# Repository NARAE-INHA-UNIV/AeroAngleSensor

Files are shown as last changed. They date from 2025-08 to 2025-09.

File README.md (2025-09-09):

# AeroAngleSensor

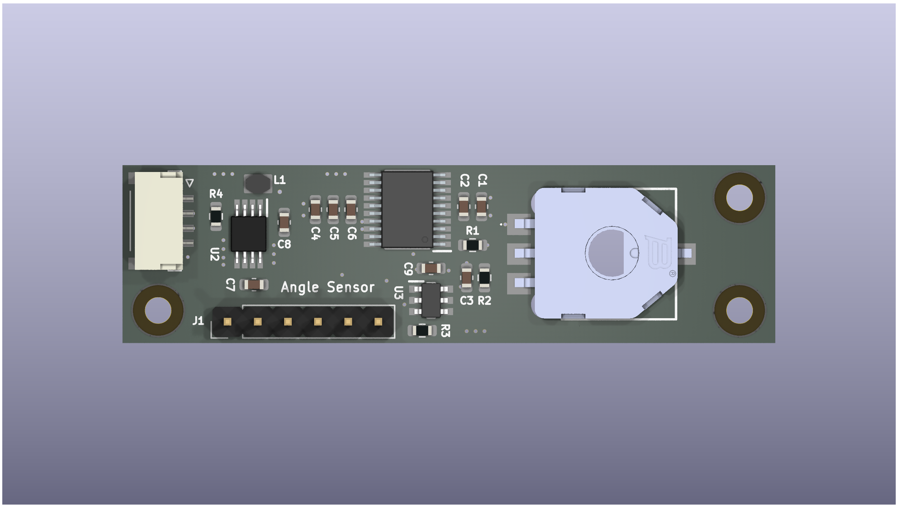
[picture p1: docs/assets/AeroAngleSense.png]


[[Youtube] 무인 항공기용 회전각 센서 시현 영상](https://www.youtube.com/watch?v=Au1dN9QMTIA)

- 일시 : 2025 1학기
- 팀명 : 항공전자, 각도발전소(인하종합설계경진대회)
- 팀장 : 김정걸
- 팀원 : 김성호, 임정섭, 이해강, 이현제

## 프로젝트 구조

```
AeroAngleSensor/
├── AeroAngleSense        # KiCAD 회로
├── AeroAngleSense.step   # 센서 step 파일
├── docs                  # docs 문서 및 이미지 에셋
├── Firmware              # 펌웨어 STM32 코드
├── LICENSE.md
├── README.md
└── Schematic.pdf
```

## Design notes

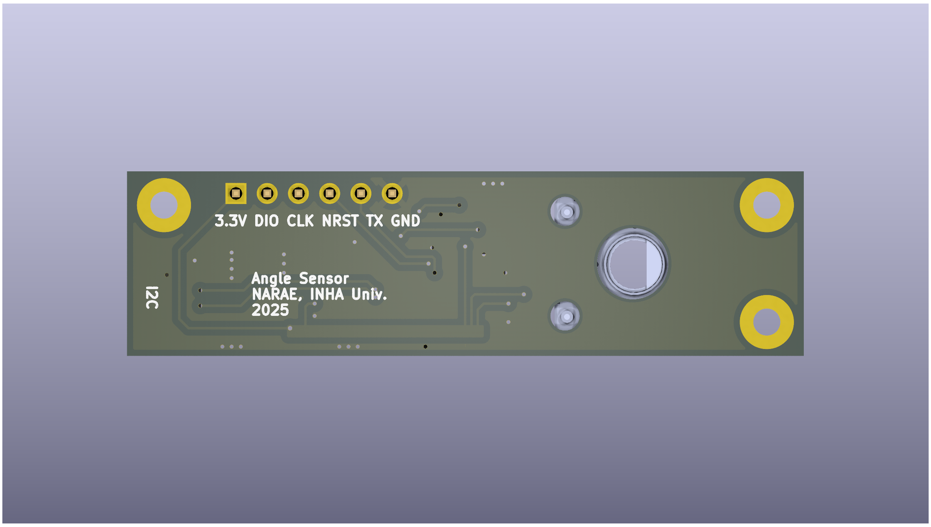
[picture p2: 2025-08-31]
docs/assets/AeroAngleSense_2.png

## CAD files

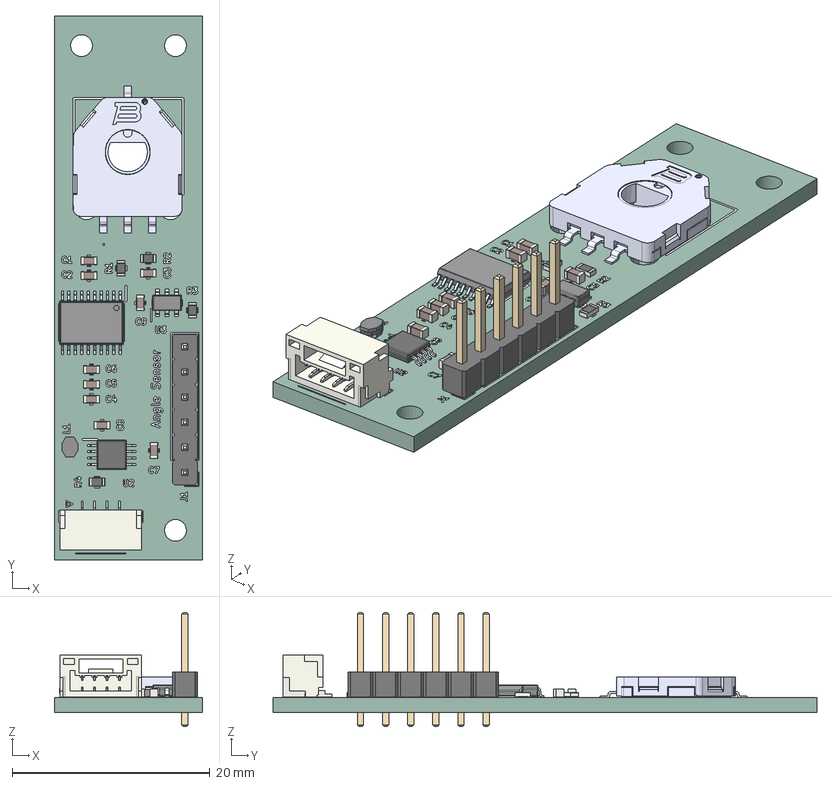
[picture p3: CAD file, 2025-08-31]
AeroAngleSense.step
15.0 x 55.0 x 11.5 mm
C_0603_1608Metric x 9
R_0603_1608Metric x 4
BODY-SOT
LEAD-SOT x 6
JST_GH_SM04B-GHS-TB_1x04-1MP_P1.25mm_Horizontal
VLS201610ET-1R5N-CA
PinsArrayLR
PinHeader_1x06_P2.54mm_Vertical
BODY-SO
LEAD-SO x 8
THERMALPAD-SO
3382G-1-103G
AeroAngleSense_silkscreen
AeroAngleSense_PCB

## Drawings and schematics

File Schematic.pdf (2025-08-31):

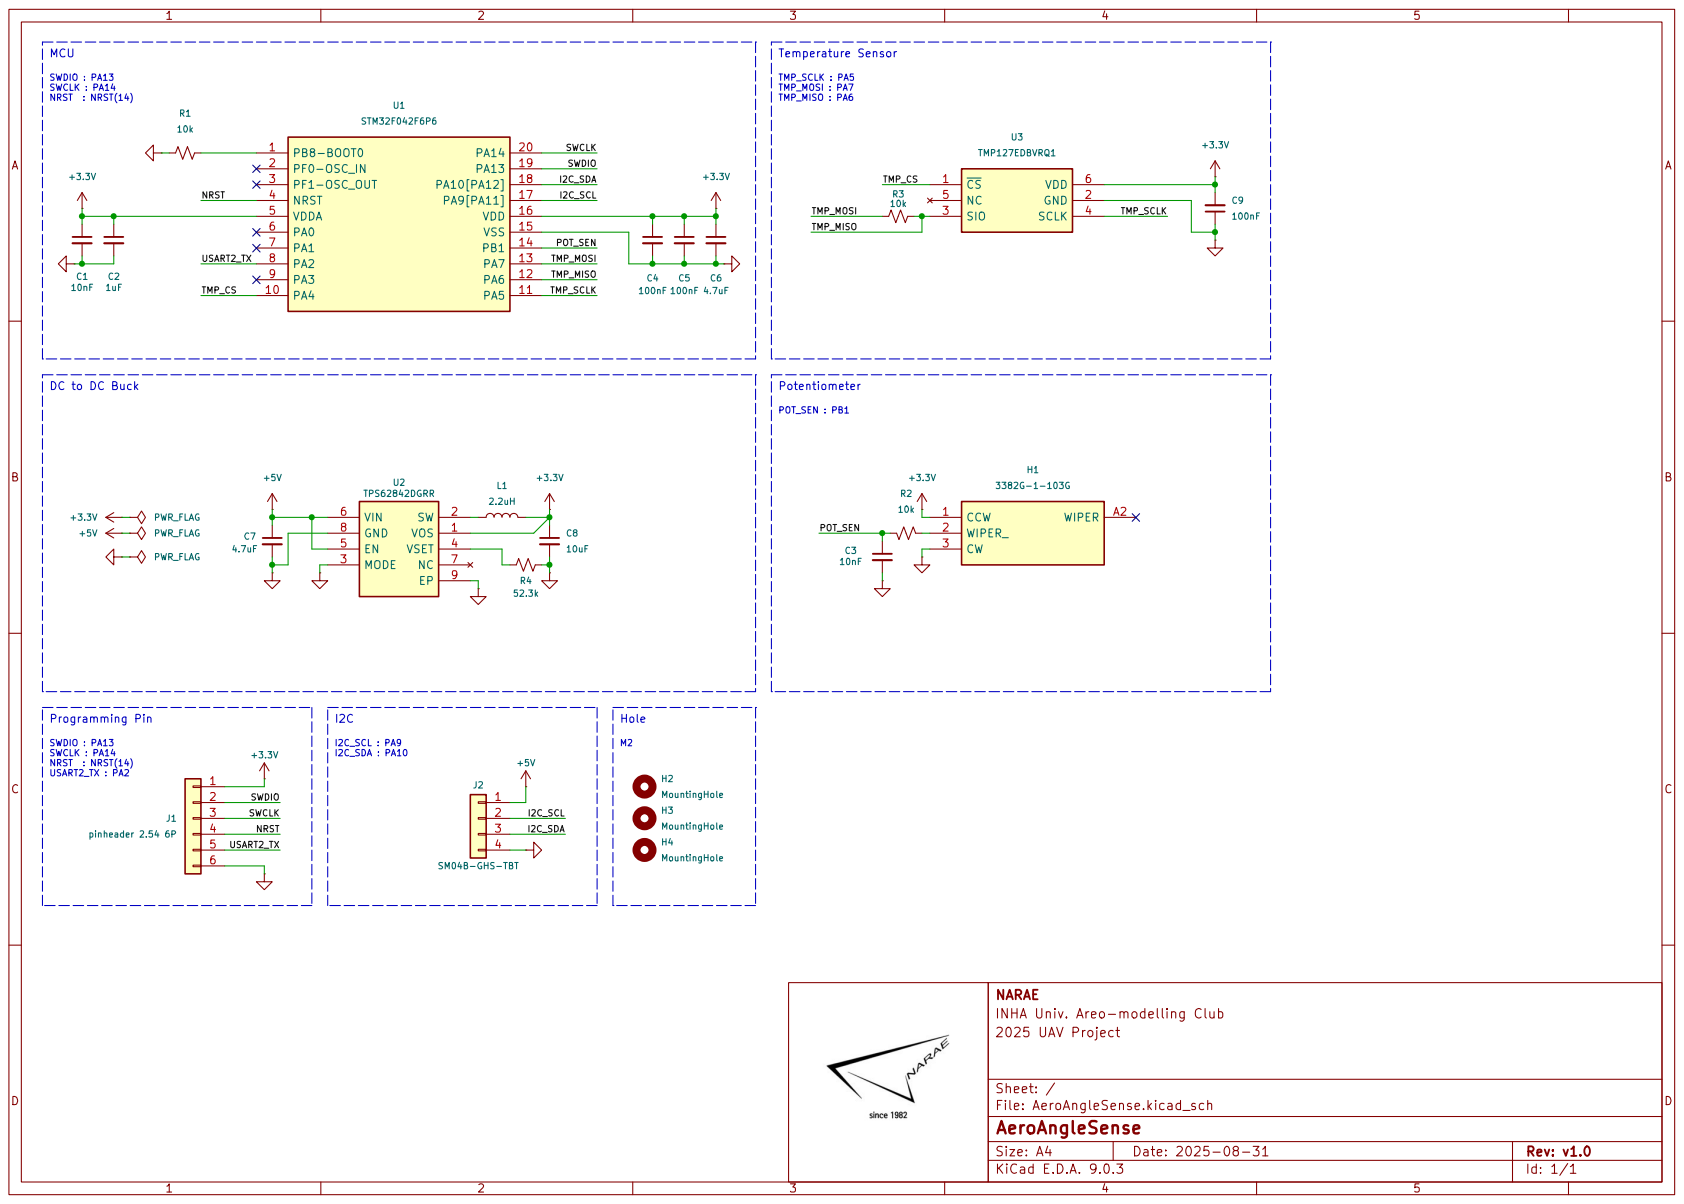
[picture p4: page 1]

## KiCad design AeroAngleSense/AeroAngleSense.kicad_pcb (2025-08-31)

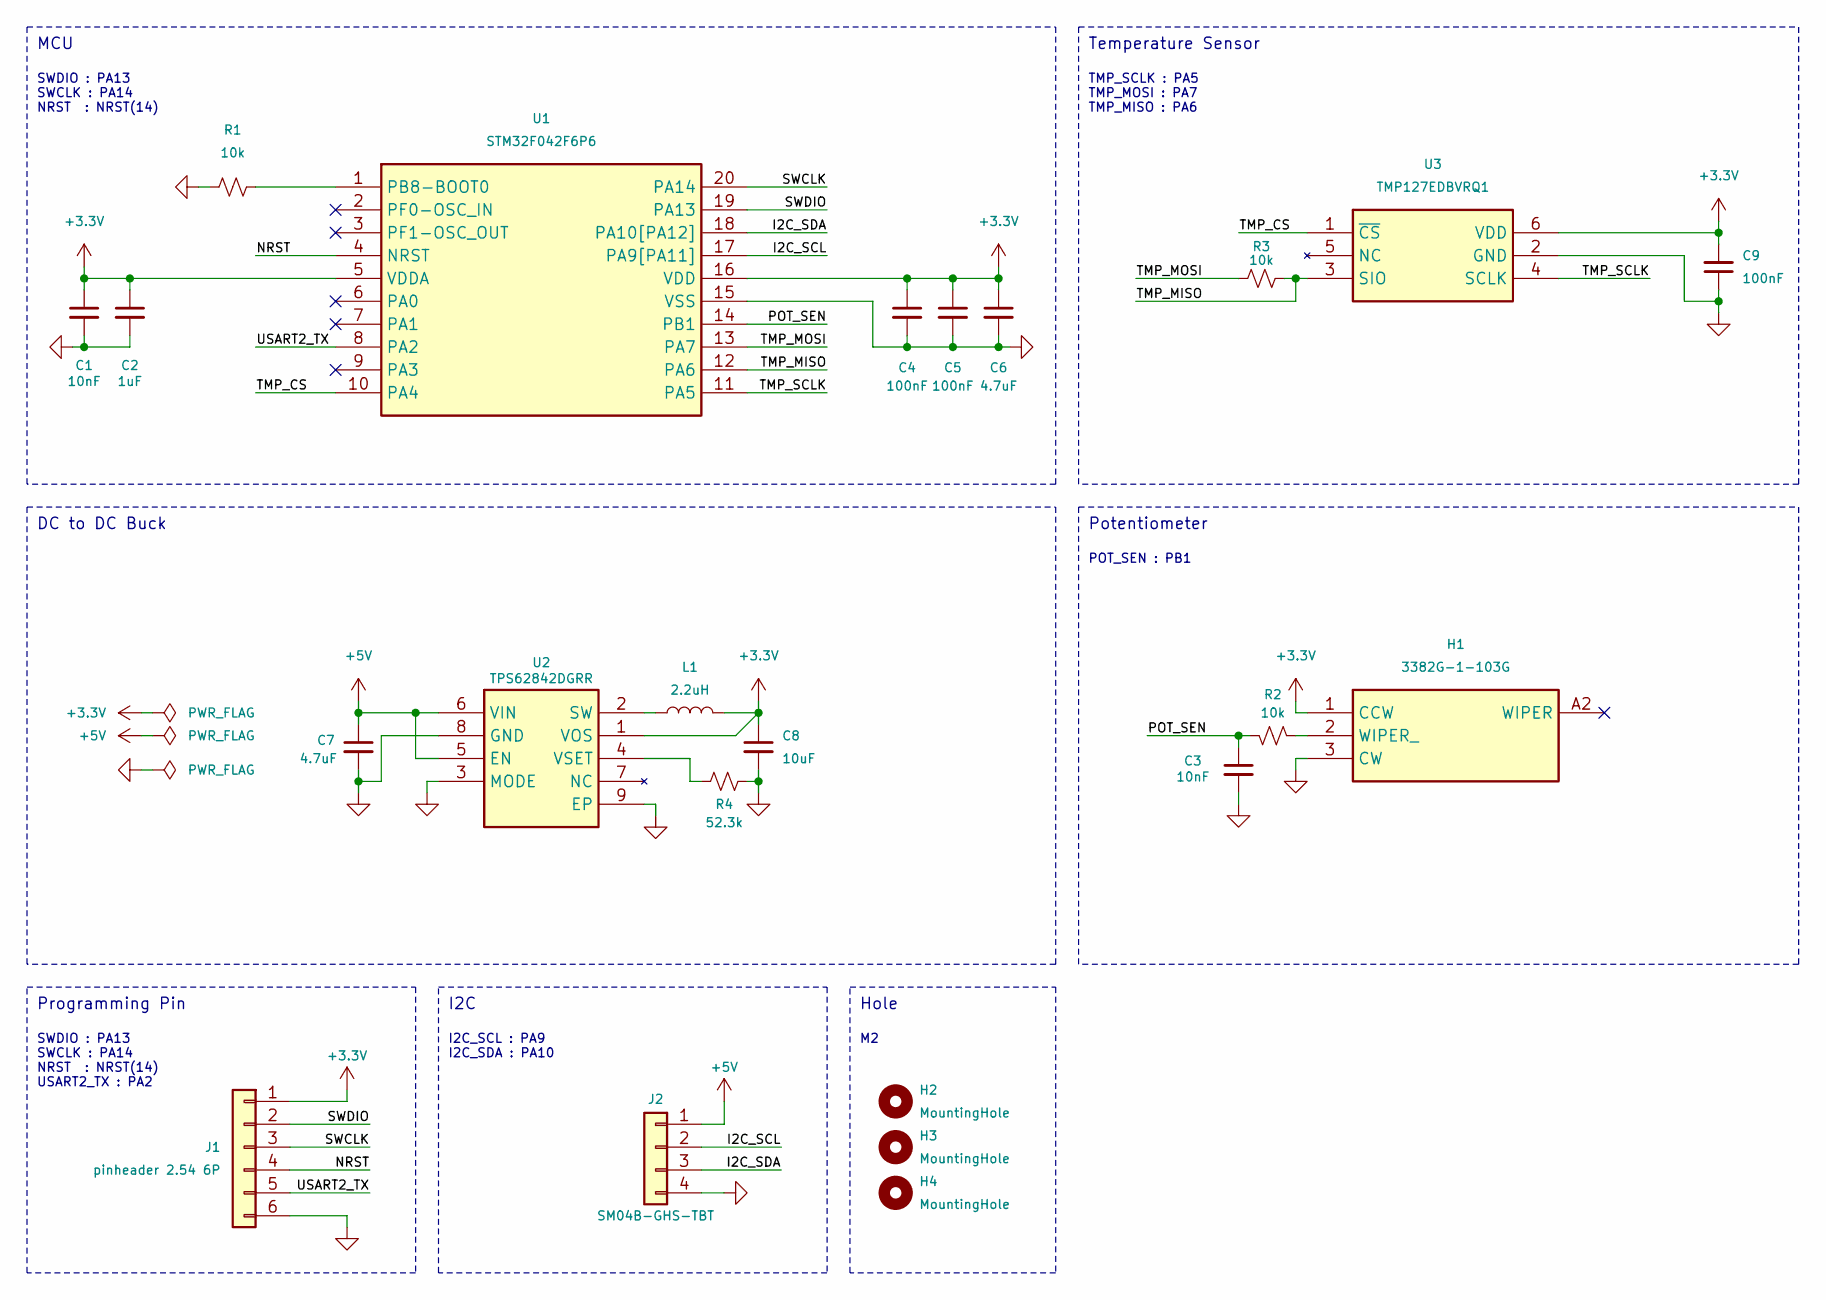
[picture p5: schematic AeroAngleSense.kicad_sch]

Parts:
C1, C3: 10nF; C_0603_1608Metric; LCSC C1589
C2: 1uF; C_0603_1608Metric; LCSC C1592
C4, C5, C9: 100nF; C_0603_1608Metric; LCSC C1590
C6, C7: 4.7uF; C_0603_1608Metric; LCSC C1705
C8: 10uF; C_0603_1608Metric; LCSC C1691
H1: 3382G-1-103G; 3382G1103G; Mouser Part Number 652-3382G-1-103G
H2, H3, H4: MountingHole; MountingHole_2.2mm_M2_Pad
J1: pinheader 2.54 6P; PinHeader_1x06_P2.54mm_Vertical
J2: SM04B-GHS-TBT; JST_GH_SM04B-GHS-TB_04x1.25mm_Angled; LCSC C189895
L1: 2.2uH; VLS201610ET-2R2M; LCSC C136230
R1, R2, R3: 10k; R_0603_1608Metric; LCSC C15401
R4: 52.3k; R_0603_1608Metric; LCSC C23198
U1: STM32F042F6P6; Manufacturer_Part_Number STM32F042F6P6; Mouser Part Number 511-STM32F042F6P6
U2: TPS62842DGRR; Mouser Part Number 595-TPS62842DGRR
U3: TMP127EDBVRQ1; SOT95P280X145-6N; Mouser Part Number 595-TMP127EDBVRQ1

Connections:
+3.3V: C1.1, C2.1, C4.1, C5.1, C6.1, C8.1, C9.2, H1.1 (CCW), J1.1, L1.2, U1.5 (VDDA), U1.16 (VDD), U2.1 (VOS), U3.6 (VDD)
+5V: C7.1, J2.1, U2.5 (EN), U2.6 (VIN)
/I2C_SCL: J2.2, U1.17 (PA9[PA11])
/I2C_SDA: J2.3, U1.18 (PA10[PA12])
/NRST: J1.4, U1.4 (NRST)
/POT_SEN: C3.1, R2.2, U1.14 (PB1)
/SWCLK: J1.3, U1.20 (PA14)
/SWDIO: J1.2, U1.19 (PA13)
/TMP_CS: U1.10 (PA4), U3.1 (~CS)
/TMP_MISO: R3.2, U1.12 (PA6), U3.3 (SIO)
/TMP_MOSI: R3.1, U1.13 (PA7)
/TMP_SCLK: U1.11 (PA5), U3.4 (SCLK)
/USART2_TX: J1.5, U1.8 (PA2)
GND: C1.2, C2.2, C3.2, C4.2, C5.2, C6.2, C7.2, C8.2, C9.1, H1.3 (CW), J1.6, J2.4, R1.1, R4.2, U1.15 (VSS), U2.3 (MODE), U2.8 (GND), U2.9 (EP), U3.2 (GND)
unnamed: H1.2 (WIPER_), R2.1
unnamed: R1.2, U1.1 (PB8-BOOT0)
unnamed: L1.1, U2.2 (SW)
unnamed: R4.1, U2.4 (VSET)

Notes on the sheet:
I2C_SCL : PA9 I2C_SDA : PA10
I2C
TMP_SCLK : PA5 TMP_MOSI : PA7 TMP_MISO : PA6
DC to DC Buck
SWDIO : PA13 SWCLK : PA14 NRST : NRST(14)
MCU
Programming Pin
Temperature Sensor
POT_SEN : PB1
SWDIO : PA13 SWCLK : PA14 NRST : NRST(14) USART2_TX : PA2
Potentiometer
Hole

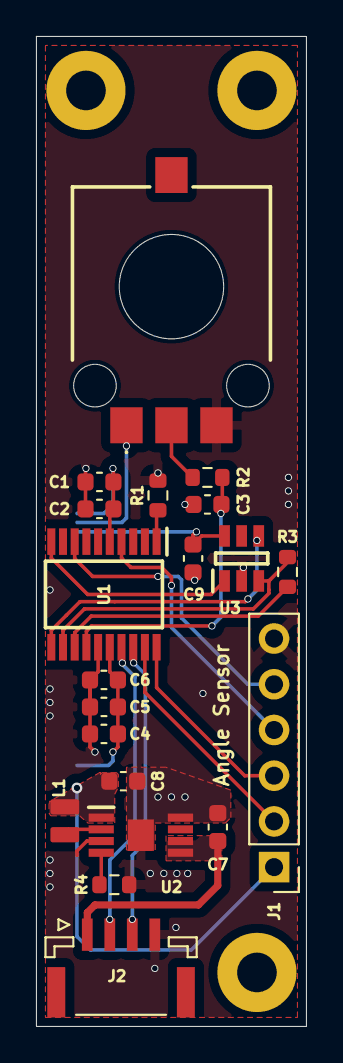
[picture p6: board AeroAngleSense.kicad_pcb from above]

Board: 2 copper layers, 15.0 x 55.0 mm, 23 parts (0 on the bottom side), 18 nets.

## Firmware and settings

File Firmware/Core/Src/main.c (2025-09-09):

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
/* Includes ------------------------------------------------------------------*/
#include "main.h"


/* USER CODE BEGIN PV */
volatile uint8_t tx_length = 0;
volatile uint8_t* tx_buffer = 0;

typedef struct __attribute__((packed)){
	uint8_t length;
	uint16_t angle_raw;
	float angle;
	float temp;
} TX_PACKET;

volatile TX_PACKET data;

/* USER CODE END PV */

void SystemClock_Config(void);
static void MX_GPIO_Init(void);
static void MX_ADC_Init(void);
static void MX_SPI1_Init(void);
static void MX_I2C1_Init(void);
static void MX_USART2_UART_Init(void);
/* USER CODE BEGIN 0 */
void I2C_TransmitBufferUpdate(uint8_t* p, uint8_t len)
{
	tx_length = len;
	tx_buffer = p;
	return;
}

/* USER CODE END 0 */

/**
 * @brief  The application entry point.
 * @retval int
 */
int main(void)
{

	/* MCU Configuration--------------------------------------------------------*/

	/* Reset of all peripherals, Initializes the Flash interface and the Systick. */
	HAL_Init();

	/* Configure the system clock */
	SystemClock_Config();

	/* Initialize all configured peripherals */
	MX_GPIO_Init();
	MX_ADC_Init();
	MX_SPI1_Init();
	MX_I2C1_Init();
	MX_USART2_UART_Init();
	/* USER CODE BEGIN 2 */
	LL_ADC_Enable(ADC1);
	LL_I2C_Enable(I2C1);
	LL_I2C_EnableIT_ADDR(I2C1);
	LL_I2C_EnableIT_RX(I2C1);
	LL_I2C_EnableIT_TX(I2C1);
	LL_I2C_EnableIT_STOP(I2C1);
	LL_I2C_EnableIT_NACK(I2C1);


	/* USER CODE END 2 */

	/* Infinite loop */
	/* USER CODE BEGIN WHILE */
	while (1)
	{
		// read ADC data
		LL_ADC_REG_StartConversion(ADC1);
		while(LL_ADC_IsActiveFlag_EOC(ADC1) == 0)
		{

		}
		LL_ADC_ClearFlag_EOC(ADC1);

		data.angle_raw = LL_ADC_REG_ReadConversionData12(ADC1);

		// data calculate
		data.length = sizeof(data);
		data.angle = data.angle_raw/4096.0f * 330;
		data.temp = 29.8f;

		I2C_TransmitBufferUpdate((uint8_t*)&data, data.length);

		/* USER CODE END WHILE */

		/* USER CODE BEGIN 3 */
	}
	/* USER CODE END 3 */
}

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


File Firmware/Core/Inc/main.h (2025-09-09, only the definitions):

#define TMP_CS_Pin LL_GPIO_PIN_4
#define TMP_CS_GPIO_Port GPIOA
#define POT_SEN_Pin LL_GPIO_PIN_1
#define POT_SEN_GPIO_Port GPIOB

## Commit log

2025-08-06 스케메틱 및 라이브러리 파일 최초 업로드
    [AeroAngleSense.kicad_pcb, AeroAngleSense.kicad_sch]
2025-08-06 kicad 초기 업로드
2025-08-12 fix:temp spi 3 wire/pot_sen symbol
    [AeroAngleSense.kicad_sch]
2025-08-12 LCSC값 추가
    [AeroAngleSense.kicad_sch]
2025-08-12 add:DEBUG&I2C conn
    [AeroAngleSense.kicad_sch]
2025-08-19 소자 배치
    [AeroAngleSense.kicad_pcb, AeroAngleSense.kicad_sch]
2025-08-19 배선 연결 작업_1
2025-08-21 pcb layout done.
    [AeroAngleSense.kicad_pcb, AeroAngleSense.kicad_sch]
2025-08-21 add : copper zone"
    [AeroAngleSense.kicad_pcb]
2025-08-22 배선 작업_1
2025-08-24 배선_2
    [AeroAngleSense.kicad_pcb]
2025-08-25 배선_3
    [AeroAngleSense.kicad_pcb]
2025-08-25 배선 최종
    [AeroAngleSense.kicad_pcb]
2025-08-25 배선_4
    [AeroAngleSense.kicad_pcb]
2025-08-28 fix : route
    [AeroAngleSense.kicad_pcb, AeroAngleSense.kicad_sch]
2025-08-28 fix : silkscreen
    [AeroAngleSense.kicad_pcb]
2025-09-09 add : firmware code - ADC, I2C send

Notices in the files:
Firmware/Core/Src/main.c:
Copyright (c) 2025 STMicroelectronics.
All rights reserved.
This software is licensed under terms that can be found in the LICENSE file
